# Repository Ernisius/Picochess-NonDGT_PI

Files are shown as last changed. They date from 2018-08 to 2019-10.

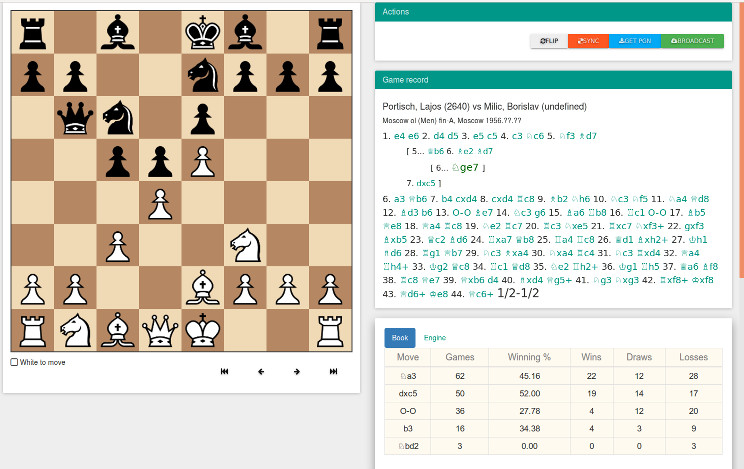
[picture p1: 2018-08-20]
test/webserver73.jpg

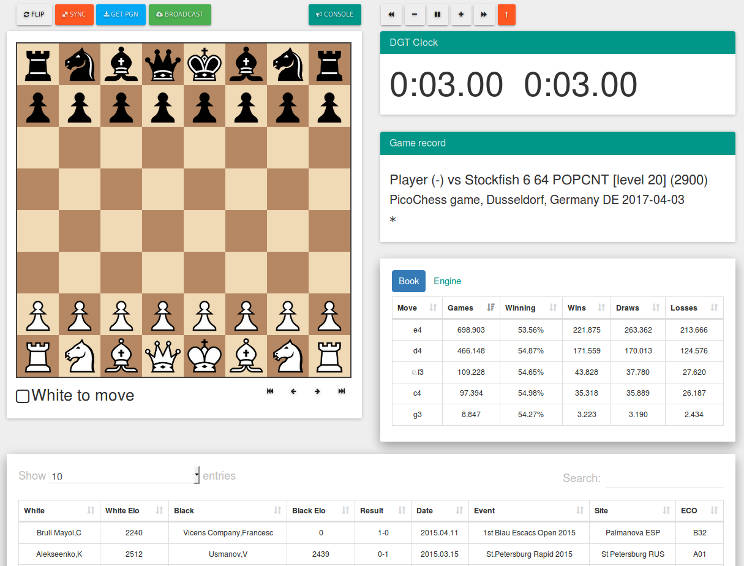
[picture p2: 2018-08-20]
test/webserver85.jpg

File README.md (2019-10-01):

PicoChess
=========

This is quite a complicated project.
I recommend you do not attempt it unless you have some knowledge of digital electronics, Arduino C programming and Python programming.
Without These skills you will find it difficult to locate any wiring or component errors.

It requires a I2c 20*4 LCD display connected to the raspberry pi via I2c.

Functionality.
To scan the reed switches, the Arduino uses a 4017 chip to set each row in turn  to + 5v, Then reads the columns into the arduino via the shift register. 
(nb It doesn't start to monitor buttons or reed matrix until it detects the pieces are set up to starting chess position, comment out the newgame line in the startup code to bypass this check.)
When a reed swith opens or closes the led for that square are flashed.
The arduino also monitors the buttons in the same way.
It sends "B:n" for a button change or move (eg "D2D4") to the pi via the usb port.

To test the board, monitor Arduino serial to make sure it is sending the expected messages.

To configure the raspberry pi follow these steps.

Download the last free picochess image from the picochess website. (version N). 
remove or rename /usr/picochess ( to stop this from autostarting when the pi boots.)
download the python code here and copy it to home on the pi.
After rebooting start with 
python3 picochess.py.

picochess is well documented on the picochess website.

When everythin is working you can move the picochess directory to /usr so it starts automatically on boot.

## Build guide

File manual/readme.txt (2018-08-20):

ShortManual.pdf contains a PicoChess manual that fits to one A4 page. Print it and 
store it under the board.

If you want to edit the file simply open ShortManual.odt. Make sure you have
the required fonts installed and at the printing dialog select PageLayout -> 
Pages per sheet = 2 and select "draw border".

Have fun.

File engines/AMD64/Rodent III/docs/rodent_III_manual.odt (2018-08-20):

Rodent III UCI

# Introduction

There are different kinds of chess engines. Some are programmed for strength. Komodo by Mark Lefer, Larry Kaufman and late Don Dailey has been able to beat human grandmasters giving them material odds. Some, like Stockfish, merge the oursuit of strength with adherence to software engineering principles. Some are programmed to prove a research hypothesis. Giraffe by Matthew Lai plays strong chess using neural networks for evaluation and highly unusual search algorithm. Some are programmed for style, like legendary Chess System Tal by Chris Whittington.

Rodent III has been programmed for tunability. You can turn it into a crazy attacker, an old-fashioned positional player, or a sparring partner for Your kids. Its tuning options are both intuitive and relevant from the chess point of view, making it a perfect free replacement of commercial programs.

# Facts and numbers

Rodent III is an open source chess engine by Pawel Koziol, licensed under GPL 3.0. It is based on a much weaker engine Sungorus 1.4 by Pablo Vazquez (https://sites.google.com/site/sungorus/). This makes it a derivative work.

Rodent III is just a chess engine, so in order to enjoy it you will need a graphical user interface (GUI). Some of possible choices are: Winboard, Arena, TarraschGUI (http://www.triplehappy.com/), ChessGUI. If You are using another GUI, You should be fine as long as it understands UCI protocol (which is usually the case, since top engines like Stockfish and Komodo use it).

Rodent's strength probably exceeds 2920 Elo on the CCRL (http://www.computerchess.org.uk/ccrl/4040/) scale. This should allow the engine to hover slightly above the 50th place on CCRL and CEGT rating lists. You can conclude that Rodent III is a decent engine, albeit far from the top dogs or from aspiring engines like Fizbo or ICE.

# Origins

Rodent III is a derivative of much weaker, yet very cleanly written engine Sungorus by Pablo Vazquez (https://sites.google.com/site/sungorus/). Its concise and logical code served as a base to add further enhancements.

Throughout the developement cycle, a lot of knowledge from other open-source programs has been added. These inspirations include (in alphabetic order):

Andscacs – penalty for bishops that cannot reach enemy half of the board

Crafty – material imbalance table

DiscoCheck – evaluation of hanging pieces (extended also to defended pieces with smaller weights).

Fruit (via Toga log user manual) – many evaluation weights, including piece square tables (PstStyle = 1 / "classic") and mobility values (MobilityStyle = 1 / "linear"). Fruit values served as reasonable first guesses and some of them were subsequently retuned.

Gambit Fruit – king tropism weights.

Hakapeliitta – basis for piece square tables ( PstStyle = 0 / "quirky" is symmetric and tweaked version of Hakapeliitta tables)

Senpai – implementation of aspiration windows and late move pruning

Stockfish – late move reduction depths, the way of initializing king safety table.

Texel – pawn island evaluation

Toga II 3.0 – razoring implementation and forwardness evaluation (in Toga II it is called "space").

# Contributors

These people helped to improve Rodent

Jim Ablett supplied Android compiles in the past

Graham Banks made a funny, cartoon-like logo

Matthew R. Brades, Denis Mendoza and Martin Sedlak supplied Linux compiles of some 1.x versions

Lucas Braesch prompted me repeteadly to maintain Linux compatibility

Dann Corbit has sent a patch allowing to use popcount intrinsics and fast 64-bit compiles, pointed some bugs.

Jon Dart supplied a Linux patch of some bitboard functions

Kestutis Gasaitis made a thorough code inspection of 0.xx versions, spotting bugs and suggesting improvements.

Raimar Goldschmidt supplied several bugfixes and created personality testing framework

Dave Kaye prepared Rodent II to be compiled under Linux

Denis Mendoza created a logo featuring Speedy Gonzales

Ferdinand Mosca created very funny KingHunter personality

Brendan J. Norman created Henny and Remy personalities and reviewed Rodent on his blog

Frank Quasinsky tested Rodent II for FCP rating list

Roman T. Sovanyan created Rodent Risky branch, and his contribution has been accepted

Pablo Vazquez has kindly allowed me to use the codebase of Sungorus to start this project

# Notes about recent release

Rodent III is a complete rewrite. It has been rather draining to do it relatively soon after a rewrite of Rodent II, but unfortunately I failed several times trying to add multicore support to that codebase.

# basic.ini

As it has been stated before, Rodent allows its users to modify several options influencing its playing style. The way of accessing all of them may seem a little clumsy. It is a result of an attempt to have the best of both worlds: instantly accessible predefined styles for a casual user and a possibility to tweak the engine for those who like it.

The choice between these scenarios must be made in basic.ini file. That file does not initialize the engine itself, but drastically changes the way how it talks to the GUI. There are two setups: "HIDE_OPTIONS" and "SHOW_OPTIONS". The first lets the user play with predefined personalities, the second – to set them manually via UCI options.

The second choice made in basic.ini relates to HIDE_OPTIONS mode only. The string "PERSONALITY_BOOKS" means that opening books are read from personality files. This works fine under Windows, but under Linux you must actually type correct paths to opening books in the personality files. The string "GENERAL_BOOKS", on the other hand, allows to set opening book independently and orders the engine to ignore book settings from personality file.

The third choice is between "ELO_SLIDER" and "NPS_BLUR". If ELO_SLIDER setting is in effect, user gets the chance to set engine's Elo via standard UCI_Elo option. If he opts for NPS_BLUR, he gets two independent parameters – nodes per second limit and the pseudo-random value added to evaluation function output. The first setting is more intuitive to use, the second one gives more liberty to the user (see hilarious "Drunk" personality with full tactical strength and hopelessly twisted evauation).

# UCI options for "HIDE_OPTIONS" mode

In "HIDE_OPTIONS" mode Rodent is initialized by a personality file, which uses the same syntax as UCI parser. Personality files can invoke the other (which may be useful if You want to change just one or two parameters). Options will be described in the section "UCI options in SHOW_OPTIONS mode" below. A sample personality will be shown on the next page.

; Marshall personality for Rodent III chess engine

; by Pawel Koziol

; hommage to Frank Marshall (1877-1944)

; very high attack, very high mobility, sacrificial, likes knights

setoption name Strength value 2737

setoption name PawnValue value 100

setoption name KnightValue value 335

setoption name BishopValue value 335

setoption name RookValue value 500

setoption name QueenValue value 1000

setoption name KeepPawn value 0

setoption name KeepKnight value 0

setoption name KeepBishop value 0

setoption name KeepRook value 0

setoption name KeepQueen value 0

setoption name BishopPair value 50

setoption name KnightPair value -10

setoption name ExchangeImbalance value 25

setoption name KnightLikesClosed value 6

setoption name RookLikesOpen value 3

setoption name Material value 90

setoption name OwnAttack value 150

setoption name OppAttack value 100

setoption name OwnMobility value 150

setoption name OppMobility value 100

setoption name KingTropism value 25

setoption name PiecePlacement value 100

setoption name PiecePressure value 100

setoption name PassedPawns value 100

setoption name PawnStructure value 90

setoption name Lines value 100

setoption name Outposts value 100

setoption name Fianchetto value 0

setoption name PawnShield value 100

setoption name PawnStorm value 100

setoption name Forwardness value 100

setoption name DoubledPawnMg value -12

setoption name DoubledPawnEg value -24

setoption name IsolatedPawnMg value -10

setoption name IsolatedPawnEg value -20

setoption name IsolatedOnOpenMg value -10

setoption name BackwardPawnMg value -8

setoption name BackwardPawnEg value -10

setoption name BackwardOnOpenMg value -8

setoption name PstStyle value 1

setoption name MobilityStyle value 0

setoption name NpsLimit value 0

setoption name EvalBlur value 0

setoption name Contempt value 0

setoption name SearchSkill value 10

setoption name SlowMover value 100

setoption name Selectivity value 175

setoption name BookFilter value 20

setoption name GuideBookFile value books/players/marshall.bin

setoption name MainBookFile value books/hist/_pre30.bin

# Available personalities

Depending on the Rodent II distribution, You will obtain a set of personalities – predefined playing styles, often together with tailormade opening books. That is where Rodent's powerful and expressive option set really shines. For user's convenience, personalities are grouped in folders. Again, not every distribution package will contain all the folders. Broad outline of what to expect is shown below.

Personalities from the folder "famous" try to reenact the famous players.

"masters" are accomplished players in 2000-2300 range.

"league" contains players in 1700-2000 Elo range, often with certain quirks.

"club" players are meant to be in 1400-1700 Elo range.

"school" players are probably 1200-1400 Elo and they are prone to tactical mistakes.

"kids" folder packs even weaker players.

"fun" folder contains rather unusual opponents, some of them quite strong, but decidedly quirky

# UCI options in SHOW_OPTIONS mode

These options can be accessed in two ways. SHOW_OPTIONS written in basic.ini asks GUI to display a full set of UCI options. Personality files also use the same syntax as the UCI options parser. Possible choices include:

## Material options:

### QueenValue, RookValue, BishopValue, KnightValue, PawnValue

material values, expressed in centipawns. Interesting effects can be obtained by slightly changing bishop, knight and rook value. It is even possible that default valuess are not perfect, and that someone might come up with a better set of parameters (if I were to guess, increasing bishop's value might help).

KeepQueen, KeepRook, KeepBishop, KeepKnight, KeepPawn

preference for a given piece for the computer side. These values should be rather low.

Usage guidelines: KeepQueen = 20 is generally a good addition for aggressive personalities, since Rodent does not evaluate king attacks for the side without a queen. KeepPawn value of 2 or 3 together with KeepKnight set at 5 and KeepBishop set at -5 should be a good starting point for a personality that likes closed positions.

BishopPair

basic bonus for a Bishop pair. Default 50 is a reasonable value.

Usage guidelines: You might lower it emulating Nimzowitsch or Tchigorin.

KnightPair

for best play this value should be negative.

Usage guidelines: making it positive has interesting, if weakening effect on engine's personality, as long as opening book allows Rodent to keep its options open.

ExchangeImbalance

this bonus is applied to a side is exchange up (having a rook against a minor piece).

Usage guidelines: Lowering it pr setting it to a negative value makes the engine more inclined to exchange sacrifices. Useful if You want to emulate Petrosian (coupled with defensive play and preference for closed positions) or Topalov (coupled with attacking play).

KnightLikesClosed

a bonus given for each pawn if a knight of the same side is present. Actually it is tuned in such a way that knight gains value with 5 or more pawns on the board, and loses otherwise. This option should generally have a single-digit value (default is 6).

Usage guidelines: KnightLikesClosed may sound like a dry, technical option, but its effects are rather interesting: increasing it causes the engine to love and cherish its knights, and in case it ends with knight(s) against bishop(s) it urges Rodent II to keep as many pawns as possible, thus keeping position closed. Predefined "Hedgehog" personality makes use of this trick.

RookLikesOpen

rooks gain power with more open files available, and therefore with less pawns on the board. Both this and the previous option come from the classic article Evaluation of material imbalances by GM Larry Kaufman.

Material

percentage of material value used in actual evaluation. This idea comes from Rhetoric chess engine.

Please note that options described above do not display a full set of bad trade penalties – and that all of them, visible or not, are scaled by Material weight to ensure consistency.

Usage guidelines: Use it with caution! 90% is enough to see a lot of pawn sacrifices without compromising playing strength, anything below that leads to much weaker, but very entertaining play style.

## Positional options

PiecePlacement

basic positional score from piece/square tables, kings not included. Explanation for non-programmers is that raising it exaggerates the effect defined by PstStyle, whereas lowering it makes engine more dependent on mobility evaluation.

OwnMobility

percentage of mobility value for engine side.

OppMobility

percentage of mobility value for non-engine side.

OwnAttack

percentage value of engine's king attack.

OppAttack

percentage value of opponent's king attack.

Usage guidelines: Mobility and attack options may be set independently to create asymmetric evaluation. This is the core of personality tuning mechanism. The engine can concentrate on carrying out own attacks, on preventing opponent's agression, on activating own pieces or on blocking enemy movements.

Fiddling with mobility can also have an interesting side effect: if opponent's mobility weight is bigger, engine will be slightly more inclined to exchange pieces. You might want to compensate this effect by using small positive values for keeping own pieces on the board.

Since Rodent's evaluation is rather speculative, value around 150 would already create a ferocious attacker. However, personalities created by Ferdinand Mosca (Kinghunter) and Brendan J. Norman (Henny, Remy) successfully use even higher values.

KingTropism

percentage of value awarded for piece proximity to enemy king. Pieces that are far get a penalty, those that are near get a bonus, different weights are used for each piece (there ar two sets: for midgame and for endgame). Exact values are derived from GambitFruit. Initially I thought that it is only a "flavour" option, but tests have shown that low values tend to score slightly better than 0.

Usage guidelines: aggressive personalities with high tropism and low tropism behave differently: the first kind amasses pieces around the enemy king, the other one shoots from afar. Negative king tropism might make sense for certain positional personalities (Petrosian rather than Nimzowitsch), but its impact is untested.

PiecePressue

weight for a bonus for attacking enemy pieces.

PawnStructure

percentage of penalty for isolated, backward and doubled pawns, as well as for pawns supporting each other (defended or standing side by side).

Usage guidelines: Increasing this option results in more tight game and may be suitable for some of the positional personalities.

PassedPawns

percentage of bonus for passed and candidate passed pawns. Engine increases this bonus for connected passers, decreases it for blocked passers and makes a correction for control of a stop square.

Outposts

weight of a bonus for occupying good squares immune from attacks by enemy pawns or defended by own pawns. This deals with positioning of minor pieces.

Usage guidelines: this value might be increased for positional personalities, but it is not strictly necessary.

Lines

weight of a bonuses for open files, semi-open files and major pieces on the 7th rank.

Pawn shield

this option determines engine's desire to protect king with own pawns.

Pawn storm

this option determines the willingness to attack enemy king with pawns.

Forwardness

this option determines the bonus for placing pieces on enemy half of the board (generally: the more, the merrier and stronger pieces have bigger weight)

Fianchetto

Bonus for a fianchetoed bishop near own king. Default is 0, but even ludicrously high values like 50 tend to test rather well.

Pst style

this option is rather difficult to describe – it makes the engine choose between three different sets of piece/square tables. These are the backbone of evaluation function, telling which piece belongs where. The available choices are likely to be expanded, but for now three distinct styles are available:

Number in UCI options dialog | Name in personality creator | About
0 | quirky | dynamic, likes advancing edge pawns
1 | classic | likes to centralize pieces
2 | normal | balanced style
3 | blunt | Weaker, primitive, centralizing

MobilityStyle

This options gives two possiblilties. Mobility can be either linear (gain from 1 to 2 possible moves is the same as from 7 to 8) or decreasing (improving low mobility scores comes before improving high mobility scores). In personality creator, we use the aforementioned names, in UCI options dialog 0 is linear and 1 is decreasing.

## Other options

BookFilter

irrelevant for eval tuning, influences usage of Polyglot books by eliminating moves with the value lesser than a given percentage of best move's value. Read more in "Opening book" section.

NPS

nodes per second. This option is meant to slow the engine down, and used to create weak personalities. This needs more testing, but NPS of about 5000 puts Rodent II somewhere within the 1600-1800 Elo range (FIDE scale).

EvalBlur

Random value added to evaluation function, used to create weak personalities.

Contempt

Represents the unwillingness to draw. For example, value "12" means that in the opening position Rodent will prefer to be 11 centipawns behind than to accept a draw by repetition.

SlowMover

percentage modifier for time usage. Values < 100 make the engine play faster at the beginning of the game, values > 100 make it use more time.

SearchSkill

Another way of weakening the engine. Search skill lower than 10 means that certain search techniques are disabled.

Search skill 1 – transposition table enabled

Search skill 2 – null move enabled

Search skill 3 – LMR of quiet moves enabled

Search skill 4 – razoring enabled

Search skill 5 – futility pruning enabled

Search skill 6 – late move pruning enabled

Search skill 7 – aspiration window enabled

Search skill 8 – static null move enabled

Search skill 9 – reduction of bad captures

Search skill 10 – null move verification

RiskyDepth

Contribution from Roman T. Savonyan. If above 0, it denotes depth at which score is modified by a formula that makes engine to like risky continuations.

Selectivity

Determines how often Rodent uses pruning and reduction heuristics at move level. This option affects late move reduction, late move pruning and futility pruning, but has no effect on null move pruning and razoring. Minimum value of 0 switches these techniques off, maximum value of 200 means using them on any eligible move. Values in between indicate how often a move that has been successfull in the past searches is exempt from pruning. Default value is 175.

Usage guidelines: Default has been tested to be stronger than 150 and 200. Values around 100 can be used to emulate primarily positional players.

# Describing personalities

When creating new personality for Rodent II, it might be a good idea to prepare a description, telling the user what to expect. Description can be brief (just a couple of adjectives) or more "artistic" (describing a set of parameters as if it was a human character). Here I propose a couple of terms. Please treat them as guidelines, not as

Proposed term | Meaning
active | OwnMobility increased
restricting, grinder | OppMobility increased
aggressive | OwnAttack increased
careful, prophylactic | OppAttack increased
dynamic | both OwnAttack and OwnMobility increased
materialist | MaterialWeight > 100
sacrificing | MaterialWeight at about 90
romantic | MaterialWeight < 90
classical | PiecePlacement > 100
improvising | PiecePlacement < 100
solid | PawnStructure > 100, possibly also Outposts > 100
undervalues/overvalues X | piece value different from default
likes blocked positions | KnightLikesClosed > 6 KeepPawn > 0
moderate | NPSLimit at about 2000
weak | NPSLimit < 1000
careless | high evalBlur
fast | MoveTime < 100
slow | MoveTime > 100

# Opening book

Rodent uses two Polyglot (*.bin) books in succession. The idea behind this design is that first book may be a narrow, handmade repertoire book, whereas the second one, usually bigger and more general, constitutes a fallback option.

Rodent has a unique feature allowing it to filter moves that would be used with the frequency lower than n% of best move frequency. Default settings use n = 10. If you set it to 100%, engine will pick only the book moves played with the greatest frequency. Most of the time it will be just one move, sometimes two or three. When using rodent.bin, 50% will give you a narrow book exploring only major alternatives.

Elo | NPS | Rejected version – weak below 2000 | Blur
1000 | 50 | 54 | 200
1100 | 130 | 58 | 180
1200 | 210 | 64 | 160
1300 | 290 | 72 | 140
1400 | 370 | 98 | 120
1500 | 450 | 128 | 100
1600 | 660 | 186 | 80
1700 | 740 | 303 | 60
1800 | 1000 | 540 | 40
1900 | 2000 | 1007 | 20
2000 | 4000 | 3800 | 0
2100 | 8000 | 7560 | 0
2200 | 16000 | 15051 | 0
2300 | 32000 | 30000 | 0
2400 | 64000 | 60000 | 0
2500 | 128000 | 241000 | 0
2600 | 256000 | 482000 | 0
2700 | 512000 | 964000 | 0
2800 | 1mln+ | 1 mln+ | 0

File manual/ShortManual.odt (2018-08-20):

## Choosing opening books (selection with black queen)

Opening books are set with the extra M. (Remove the extra m if it is still on the board)

Ma3 | Mb3 | Mc3 | Md3 | Me3 | Mf3 | Mg3 | Mh3
No book | ECO A – Flank Openings | ECO B – Semi Open Openings | ECO C – Open Openings | ECO D – Closed Openings | ECO E – Indian Openings | Fun Book | Varied (Default)
Ma4 | Mb4 | Mc4 | Md4 | Me4 | Mf4 | Mg4 | Mh4
GM games | Perfor-mance | Stockfish optimized | Anand book | Korchnoi book | Larsen book | Pro book | GM 2001

## Setting up time controls (selection with white queen)

You can choose them by placing the extra m. (Remove the extra M if it is still on the board). Blitz 5 minutes per game is set as default.

### Movetime (seconds per move)

ma6 | mb6 | mc6 | md6 | me6 | mf6 | mg6 | mh6
1 sec | 3 sec | 5 sec | 10 sec | 15 sec | 30 sec | 60 sec | 90 sec

### Gametime (minutes per game)

ma4 | mb4 | mc4 | md4 | me4 | mf4 | mg4 | mh4
1 min | 3 min | 5 min | 10 min | 15 min | 30 min | 60 min | 90 min

### Fischer Time (minutes per game plus an increment per move)

ma3 | mb3 | mc3 | md3 | me3 | mf3 | mg3 | mh3
1 min plus 1 sec inc | 3 min plus 2 sec inc | 5 min plus 3 sec inc | 10 min plus 5 sec inc | 15 min plus 10 sec inc | 30 min plus 15 sec inc | 60 min plus 20 sec inc | 90 min plus 30 sec inc

## Engine selection (selection with black queen)

Ma6 | Mb6 | Mc6 | Md6 | Me6 | Mf6 | Mg6 | Mh6
Stockfish 8 | Texel 1.07 | Arasan 20.3 | Rodent III 0.233 | Zurichess neuchatel | WyldChess 1.5 | Galjoen 0.37 | Sayuri 2017.12.16

## Choosing skill level (selection with black queen)

Put the extra M on your DGT board to select skill level. If no skill level is selected, PicoChess uses the highest level by default. (Remove the extra m if it is still on the board). Please note that not all chess engines support levels.

Ma5 | Mb5 | Mc5 | Md5 | Me5 | Mf5 | Mg5 | Mh5
Level 0 (Stockfish) | Level 3 (Stockfish) | Level 6 (Stockfish) | Level 9 (Stockfish) | Level 12 (Stockfish) | Level 15 (Stockfish) | Level 18 (Stockfish) | Level 20 (Stockfish)

## Playing / Training Modes (selection with white queen)

When using these modes, please be patient and don’t rush moves. Allow a few seconds for the scores and moves to appear.

Game mode is enabled by putting ma5 square. This is the default mode. You can play against the computer.

Brain mode is enabled by putting mb5 square. This is similar to game mode but the computer is thinking on your time too. This system is also known as „Permanent Brain“ therefore its name.

Analysis mode (enabled by mc5): the computer is watching the game; it does not play itself. The clock continually displays the best move for the side to play.

Kibitz mode (enabled by md5): the computer is watching the game; it does not play itself. The clock continually displays the position score together with the depth.

Observe mode (enabled by me5): the computer is watching the game; it does not play itself. The clock displays the remaining thinking time for both sides.

Ponder mode (enabled by mf5): the computer is watching the game, it does not play itself. The clock displays the best move for the side to play in rotation with the position score together with the depth.

Remote mode (enabled by mh5): this mode will allow you to play against someone over internet. The remote player using the webserver whereas the other player using the pieces as normal to enter moves.

## Start a new game

Simply place all pieces to the start position. Adjust your options (e.g. time control, strength, ...) and start playing. If you

want to play Black, press the lever on the clock.

## Update picochess

You can either set the „update flag“ inside picochess.ini or you can press the middle button during the startup when „picochess“ is displayed. This will let you choose which version you want to get (you can upgrade or downgrade). You need a working iNet connection for this to work.

## Shutdown

From the start position, replace the white n with the extra white m. This will shut down the Raspberry. It takes a few seconds until the blue light turns off. You can also do it with only the two m on the board (on e1,d1) and all other pieces removed from the board.

## Resign a game or declare draw

Placing the two kings on opposite centre squares will signal a resignation:

White wins: If both kings on white (e4,d5), the result is white wins and the game recorded 1-0

Black wins: If both kings on black (d4,e5), the result is black wins and the game recorded 0-1

Draw: Placing the kings on adjacent centre squares (d4&e4;d5&e5) on the same rank signals a draw and

the game recorded 1/2-1/2. The fourth and fith rank must be clear of other pieces - only kings.

PicoChess Short Manual v0.9l

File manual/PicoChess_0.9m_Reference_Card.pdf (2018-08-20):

PicoChess 0.9m Reference Card | January 2018

### Choosing an Engine

8 | | | rmblkans
7 | | | opopopop
6 | | | 0ZqZ0Z0Z
5 | | | Z0Z0Z0Z0
4 | | | 0Z0Z0Z0Z
3 | Z0Z0Z0Z0 2 | POPOPOPO 1 | SNAQJBMR
a | b | c | d | e | f | g | h

black queen

a6 | Stockfish 8 (‘081017’) | default
b6 | Texel 1.07
c6 | Arasan 20.3.0
d6 | Rodent iii 0.233
e6 | Zurichess neuchatel (‘master’)
f6 | WyldChess 10062017
g6 | Galjoen 0.37.2
h6 | Sayuri 2017.12.16

Example: Arasan 20.3.0

### Choosing a Level

8 | | | rmblkans
7 | | | opopopop
6 | | | 0Z0Z0Z0Z
5 | | | Z0ZqZ0Z0
4 | | | 0Z0Z0Z0Z
3 | Z0Z0Z0Z0 2 | POPOPOPO 1 | SNAQJBMR
a | b | c | d | e | f | g | h

black queen

a5 | Level 0 (= weakest)
b5 | Level 3
c5 | Level 6
d5 | Level 9
e5 | Level 12
f5 | Level 15
g5 | Level 18
h5 | Level 20 (= strongest) | default

* Not all engines support levels: Rodent iii has
‘personalities’ and Zurichess has ‘handicaps’. | Example: Level 9

### Choosing an Opening Book

black queen

a3 | No book
8 | | | rmblkans
7 | | | opopopop
6 | | | 0Z0Z0Z0Z
5 | | | Z0Z0Z0Z0
4 | | | 0Z0Z0Z0Z
3 | Z0Z0Z0l0 2 | POPOPOPO 1 | SNAQJBMR
a | b | c | d | e | f | g | h
b3 | eco A: flank openings
c3 | eco B: semiopen games
d3 | eco C: open games + French
e3 | eco D: closed games
f3 | eco E: Indian games
g3 | Fun
h3 | Varied | default
a4 | gm 1950
b4 | Performance
c4 | Stockfish
d4 | Anand
e4 | Korchnoi
f4 | Larsen | Example: Opening Book ‘Fun’
g4 | Pro
h4 | gm 2001

### Choosing a Time Control

8 | | | rmblkans
7 | | | opopopop
6 | | | 0Z0Z0Z0Z
5 | | | Z0Z0Z0Z0
4 | | | 0Z0ZQZ0Z
3 | Z0Z0Z0Z0 2 | POPOPOPO 1 | SNAQJBMR
a | b | c | d | e | f | g | h

white queen

a6 | Fixed: 1 s / move
b6 | 3 s / move
c6 | 5 s / move
d6 | 10 s / move
e6 | 15 s / move
f6 | 30 s / move
g6 | 60 s / move
h6 | 90 s / move
a4 | Blitz: 1 min / game
b4 | 3 min / game | Example: Blitz 15 min / game
c4 | 5 min / game | default
d4 | 10 min / game
8 | | | rmblkans
7 | | | opopopop
6 | | | 0Z0Z0Z0Z
5 | | | Z0Z0Z0Z0
4 | | | 0Z0Z0Z0Z
3 | L0Z0Z0Z0 2 | POPOPOPO 1 | SNAQJBMR
a | b | c | d | e | f | g | h
e4 | 15 min / game
f4 | 30 min / game
g4 | 60 min / game
h4 | 90 min / game
a3 | Fischer: 1 min + 1 s / move
b3 | 3 min + 2 s / move
c3 | 5 min + 3 s / move
d3 | 10 min + 5 s / move
e3 | 15 min + 10 s / move
f3 | 30 min + 15 s / move
g3 | 60 min + 20 s / move
h3 | 90 min + 30 s / move | Example: Fischer 1 min + 1 s / move

### Choosing a Play Mode

8 | | | rmblkans
7 | | | opopopop
6 | | | 0Z0Z0Z0Z
5 | | | L0Z0Z0Z0
4 | | | 0Z0Z0Z0Z
3 | Z0Z0Z0Z0 2 | POPOPOPO 1 | SNAQJBMR
a | b | c | d | e | f | g | h

white queen

a5 | Play against computer | default
b5 | Brain mode
c5 | Analysis mode
d5 | Kibitz mode
e5 | Observe mode
f5 | Ponder mode
h5 | Remote mode

Example: Play against computer

### Adjudicating a Game

8 | | | 0Z0Z0s0Z
7 | | | ZrZ0ZBSp
6 | | | pZpZ0Z0Z
5 | | | Z0Z0j0Z0
4 | | | 0Z0J0Z0Z
3 | O0ZPZ0Z0 2 | 0O0Z0Z0Z 1 | Z0Z0Z0Z0
a | b | c | d | e | f | g | h

both kings

First, clear the fourth and fifth ranks.
Then, place both kings:
- on e4 and d5 = White wins
- on d4 and e5 = Black wins
- on d4 and e4 = draw
- on d5 and e5 = draw

Example: Black wins

### Shut Down the Computer

8 | | | rmblkans
7 | | | opopopop
6 | | | 0Z0Z0Z0Z
5 | | | Z0Z0Z0Z0
4 | | | 0Z0Z0Z0Z
3 | Z0Z0Z0Z0 2 | POPOPOPO 1 | SNAQLBMR
a | b | c | d | e | f | g | h

white queen

In starting position,
replace the white king
with the spare white queen to power off the computer.

Also works with empty board and both white queens on
d1 and e1.

Example: Shut down computer

### Reboot the Computer

8 | | | rmblqans
7 | | | opopopop
6 | | | 0Z0Z0Z0Z
5 | | | Z0Z0Z0Z0
4 | | | 0Z0Z0Z0Z
3 | Z0Z0Z0Z0 2 | POPOPOPO 1 | SNAQJBMR
a | b | c | d | e | f | g | h

black queen

In starting position,
replace the black king
with the spare black queen to reboot the computer.

Also works with empty board and both black queens on
d8 and e8.

Example: Reboot computer

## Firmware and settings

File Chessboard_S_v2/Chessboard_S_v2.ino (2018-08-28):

#include "Adafruit_LEDBackpack.h"
#include <Wire.h>
#include "Adafruit_GFX.h"


Adafruit_LEDBackpack matrix = Adafruit_LEDBackpack();

#define White 0
#define Black 1;
#define  SR_Sin  6  //4021 #3
#define  PSCont  8  //4021 #9
#define  SR_SCLK  7  //4021 #10

#define  Cntr_CLK 4   //4017 #14
#define  Cntr_CLR 5   //4017 #15  //4017 #13 grnd

#define B1 2
#define B2 3
#define B3 11
#define B4 12

#define Enc_In1 9
#define Enc_In2 10

//for encoders
#define DIR_CCW 0x10
#define DIR_CW 0x20

const unsigned char ttable[7][4] = {            //for encoders
  {0x0, 0x2, 0x4, 0x0}, {0x3, 0x0, 0x1, 0x10},
  {0x3, 0x2, 0x0, 0x0}, {0x3, 0x2, 0x1, 0x0},
  {0x6, 0x0, 0x4, 0x0}, {0x6, 0x5, 0x0, 0x20},
  {0x6, 0x5, 0x4, 0x0},
};
int speakerPin = 13;

int numTones = 10;
int tones[] = {261, 277, 294, 311, 330, 349, 370, 392, 415, 440};
//            mid C  C#   D    D#   E    F    F#   G    G#   A

char * boardsquare[] = {"A1", "B1", "C1", "D1", "E1", "F1", "G1", "H1",
                        "A2", "B2", "C2", "D2", "E2", "F2", "G2", "H2",
                        "A3", "B3", "C3", "D3", "E3", "F3", "G3", "H3",
                        "A4", "B4", "C4", "D4", "E4", "F4", "G4", "H4",
                        "A5", "B5", "C5", "D5", "E5", "F5", "G5", "H5",
                        "A6", "B6", "C6", "D6", "E6", "F6", "G6", "H6",
                        "A7", "B7", "C7", "D7", "E7", "F7", "G7", "H7",
                        "A8", "B8", "C8", "D8", "E8", "F8", "G8", "H8"
                       };
int move_to, move_from;
bool computermove = false;
int keychanged;
int buttonmask;
bool lifted;
int boardmatrix[64];     //kb matrix

unsigned long lastDebounceTime = 0;  // the last time the output pin was toggled
unsigned long debounceDelay = 200;    // the debounce time; increase if the output flickers

void setup()
{
  pinMode(SR_Sin , INPUT);
  pinMode(PSCont, OUTPUT);
  pinMode(SR_SCLK, OUTPUT);

  pinMode(Cntr_CLK, OUTPUT);
  pinMode(Cntr_CLR, OUTPUT);

  pinMode(Enc_In1, INPUT_PULLUP);
  pinMode(Enc_In2, INPUT_PULLUP);

  pinMode(B1, INPUT_PULLUP);
  pinMode(B2, INPUT_PULLUP);
  pinMode(B3, INPUT_PULLUP);
  pinMode(B4, INPUT_PULLUP);

  Serial.begin(115200);
  Serial.setTimeout(50);
  matrix.begin(0x70);  // pass in the address
  matrix.clear();
  //matrix.blinkRate(HT16K33_BLINK_2HZ);

  newgame(White);
  fillMatrix();
  matrix.writeDisplay();
}

void loop()
{

  bool buttonEnable = true;
  long buttonDelay;

  FromPython();

  if (KeyChanged())
  {
    //Serial.print(keychanged);

    FlashSquare(keychanged, 100);
    if (computermove)
    {
      MakeComputerMove(keychanged);
    }
    else
    {
      MakeUserMove(keychanged);
    }

    if (!lifted)
    {
      //Serial.println( " dropped");
      CheckBoardPosition();
    }
    // else Serial.println(" Lifted");
  }

  rotary_process();

  GetButtonMask();
}
void MakeComputerMove(int square)
{
  if (lifted)
  {
    if (square == move_from)
    {
      // beep(450, 100);
      LightSquare(move_to, true);
      matrix.writeDisplay();
    }
    else if (square == move_to)  //remove taken piece
    {
      //do nothing
    }
    else
    {
      //beep(550, 150);
      //beep(450, 100); //wrong
    }
  }

  else   //dropped
  {
    if (square == move_to)
    {
      // beep(350, 100);
      matrix.clear();
      matrix.writeDisplay();
      computermove = false;
      ToPython("Done");
    }
  }
}
void MakeUserMove(int square)
{
  static bool startsquare;
  if (lifted)
  {
    if (!startsquare)
    {
      //beep(500, 100);
      LightSquare(square, true);
      matrix.writeDisplay();
      move_from = square;
      startsquare = true;
    }
    else
    {
      // remove oppenents piece
    }
  }
  else  //dropped
  {
    if (move_from != square)    //!put back on same square
    {
      matrix.clear();
      String move = boardsquare[move_from];
      ToPython(move + boardsquare[square]);
      FlashSquare(square, 100);
      //beep(400, 100);
    }
    else
    {
      FlashSquare(square, 100);  //dropped on same square
      //beep(300, 200);
    }
    startsquare = false;
  }
}
void GetButtonMask()
{
  if (millis() < lastDebounceTime + debounceDelay) return;
  static int mask;
  int switchvalue = 0;
  if (digitalRead(B1) == 0) switchvalue = switchvalue | 0b10000; //b:4
  if (digitalRead(B2) == 0) switchvalue = switchvalue | 0b1; //b:0
  if (digitalRead(B4) == 0) switchvalue = switchvalue | 0b100000; //b:5
  if (digitalRead(B3) == 0) switchvalue = switchvalue | 0b100; //b:2
  if (switchvalue != mask)
  {
    mask = switchvalue;
    lastDebounceTime = millis();
    switch (mask)
    {
      case 1:
        Serial.println("b:0");
        break;
      case 4:
        Serial.println("b:2");
        break;
      case 16:
        Serial.println("b:4");
        break;
      case 32:
        Serial.println("b:5");
        break;
      default:
        break;
    }
  }
}
void ToPython(String s)
{
  Serial.println(s);// write a string
}

void FromPython()
{
  if (Serial.available() > 2)
  {
    char data = Serial.read();

    if (data == 'F')    //from computer 'from square'
    {
      computermove = true;
      move_from = Serial.parseInt();
      LightSquare(move_from, true);
      matrix.writeDisplay();
    }
    if (data == 'T')  //from computer 'to square'
    {
      move_to = Serial.parseInt();
      computermove = true;

    }
  }
}

bool KeyChanged()
{
  int key = checkmatrix();
  if (key != 99)
  { //key changed

    boardmatrix[key] = newState;
    keychanged = key;
    if (newState == 1) lifted = false;
    else lifted = true;
    return true;
  }
  return false;
}

bool GetKeyState(int key)
{
  //int c = key / 8;
  // int r = key & 0x7;
  if (boardmatrix[key] == 1) return true;
  else return false;
}

int checkmatrix()
{
  static int lastkey;
  int key = 0;

  digitalWrite(Cntr_CLR, HIGH); //reset 4017
  digitalWrite(Cntr_CLR, LOW);

  for (int row = 0; row < 8; row++)
  {
    digitalWrite(Cntr_CLK, HIGH);  //clock 4017 -use outputs 1-9 ; not 0
    digitalWrite(Cntr_CLK, LOW);

    digitalWrite(PSCont, HIGH);   //latch paralel data
    digitalWrite(PSCont, LOW);
    for (int column = 7; column >= 0; column--)
    {
      int data = digitalRead(SR_Sin);
      if (data != boardmatrix[row * 8 + column])
      {
        key = (row * 8 + column);
        if (key == lastkey)
        {
          newState = data;
          lastkey = 0;
          return (key);
        }
        else
        {
          lastkey = key;
        }
      }
      digitalWrite(SR_SCLK, HIGH);            //next bit
      digitalWrite(SR_SCLK, LOW);
    }
  }
  //digitalWrite(Cntr_CLR, HIGH); //reset 4017
  //digitalWrite(Cntr_CLR, LOW);
  return (99);
}

// reads the current switch states into matrix
void fillMatrix()
{
  digitalWrite(Cntr_CLR, HIGH); //reset 4017
  digitalWrite(Cntr_CLR, LOW);

  for (int row = 0; row < 8; row++)
  {
    digitalWrite(Cntr_CLK, HIGH);  //clock 4017 -use outputs 1-9 ; not 0
    digitalWrite(Cntr_CLK, LOW);

    digitalWrite(PSCont, HIGH);   //latch paralel data
    //PORTB = PORTB | B00000001;
    //delayMicroseconds(1);
    digitalWrite(PSCont, LOW);
    //PORTB = PORTB & B11111110;
    for (int column = 7; column >= 0; column--)
    {
      int data = digitalRead(SR_Sin);
      boardmatrix[row * 8 + column] = data;

      // PORTD = PORTD | B10000000;
      //delayMicroseconds(1);
      digitalWrite(SR_SCLK, HIGH);            //next bit
      //PORTD = PORTD & B01111111;
      digitalWrite(SR_SCLK, LOW);
    }
  }
}
void  lightled(int row, int column, bool on)
{
  if (column < 8)
  {
    if (on) matrix.displaybuffer[column] |= (1 << row);
    else matrix.displaybuffer[column] &= ~(1 << row);
  }
  else if (row < 8) //column 8
  {
    if (on) matrix.displaybuffer[row] |= (1 << 9);
    else matrix.displaybuffer[row] &= ~(1 << 9);
  }
  else  //column and row 8
  {
    if (on) matrix.displaybuffer[0] |= (1 << 10);
    else matrix.displaybuffer[0] &= ~(1 << 10);
  }
}

void FlashSquare(int square, int milliseconds)
{
  matrix.clear();
  LightSquare(square, true);
  matrix.writeDisplay();
  //beep(350,milliseconds);
  delay(milliseconds);
  LightSquare(square, false);
  matrix.writeDisplay();
}

void  LightSquare(int square, bool on)
{
  int row = int (square / 8);
  int column = square & 7;
  lightled(row, column, on);
  lightled(row + 1, column, on);
  lightled(row, column + 1, on);
  lightled(row + 1, column + 1, on);
  matrix.writeDisplay();
}

//void beep(int note1, int lengh)
//{
//  tone(speakerPin, note1);
//  delay(lengh);
//  noTone(speakerPin);
//  //delay(100);
//  //tone(speakerPin, note2);
//  //delay(50);
//  //noTone(speakerPin);
//
//}
void rotary_process()
{

  static int rpState;

  unsigned char pinstate = ((bitRead(PINB, 1)) << 1) | bitRead(PINB, 2); //Digitalpin 9&10
  rpState = ttable[rpState & 0xf][pinstate];


  if ((rpState & 0x30) == 16)
  {
    ToPython("B:3\n");

  }
  else if ((rpState & 0x30) == 32)
  {
    ToPython("B:1\n");

  }
}

void newgame(int color)
{
  int brdsetup = 0;

  while (brdsetup < 32)
  {
    fillMatrix(); //piece positions to matrix
    bool on;
    matrix.clear();

    brdsetup = 32;
    for (int i = 0; i < 16; i++)
    {
      if (!GetKeyState(i))
      {
        brdsetup--;
        LightSquare(i, true);
      }
    }
    for (int i = 48; i < 64; i++)
    {
      if (!GetKeyState(i))
      {
        brdsetup--;
        LightSquare(i, true);
      }
    }
    matrix.writeDisplay();
  }
  //
  //    beep(400, 50);
  //    delay(500);
  //    beep(400, 50);
  //    delay(500);
  //    beep(440, 300);
  computermove = false;
  if (color)   ToPython("newgame:b");
  else ToPython("newgame:w");
}
//'RNBKQBNR/PPPPPPPP/8/8/8/8/pppppppp/rnbqqbnr' = REBOOT


void CheckBoardPosition()
{
  fillMatrix(); //piece positions to matrix
  int squarecount = 0;
  for (int square = 0; square < 16; square++)
  {
    if (boardmatrix[square] == 1) //occupied
    {
      squarecount++;
      //LightSquare(row * 8 + column, true);
    }
  }
  for (int square = 48; square < 64; square++)
  {
    if (boardmatrix[square] == 1) //occupied
    {
      squarecount++;
      //LightSquare(row * 8 + column, true);
    }
  }

  if (squarecount == 32)
  {
    if (boardmatrix[16] == 1)
    {
      ToPython("shutdown");  //reboot
    }
    else if (boardmatrix[17] == 1)
    {
      ToPython("reboot");  //reboot
    }
    else
    {
      computermove = false;
      ToPython("newgame:w");
    }

  }
}

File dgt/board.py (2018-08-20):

# Copyright (C) 2013-2018 Jean-Francois Romang (jromang@posteo.de)
#                         Shivkumar Shivaji ()
#                         Jürgen Précour (LocutusOfPenguin@posteo.de)
#
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
import struct
import logging
import subprocess
from threading import Timer, Lock
#from fcntl import fcntl, F_GETFL, F_SETFL
#from os import O_NONBLOCK, read, path, listdir
from serial import Serial, SerialException, STOPBITS_ONE, PARITY_NONE, EIGHTBITS
import time

from dgt.util import DgtAck, DgtClk, DgtCmd, DgtMsg, ClockIcons, ClockSide, enum
from dgt.api import Message, Dgt
from utilities import RepeatedTimer, DisplayMsg, hms_time


class DgtBoard(object):

    """Handle the DGT board communication."""

    def __init__(self, device: str, disable_revelation_leds: bool, is_pi: bool, disable_end: bool, field_factor=0):
        super(DgtBoard, self).__init__()
        self.given_device = device
        self.device = device
        # rev2 flags
        self.disable_revelation_leds = disable_revelation_leds
        self.enable_revelation_pi = False
        self.is_revelation = False

        self.is_pi = is_pi
        self.disable_end = disable_end  # @todo for test - XL needs a "end_text" maybe!
        self.field_factor = field_factor % 10

        self.serial = None
        self.lock = Lock()  # lock the serial write
        self.incoming_board_thread = None
        self.lever_pos = None
        # the next three are only used for "not dgtpi" mode
        self.clock_lock = False  # serial connected clock is locked
        self.last_clock_command = []  # Used for resend last (failed) clock command
        self.enable_ser_clock = None  # None = "unknown status" False="only board found" True="clock also found"
        self.watchdog_timer = RepeatedTimer(1, self._watchdog)
        # bluetooth vars for Jessie upwards & autoconnect
        self.btctl = None
        self.bt_rfcomm = None
        self.bt_state = -1
        self.bt_line = ''
        self.bt_current_device = -1
        self.bt_mac_list = []
        self.bt_name_list = []
        self.bt_name = ''
        self.wait_counter = 0
        # keep the last time to find out errorous DGT_MSG_BWTIME messages (error: current time > last time)
        self.r_time = 3600 * 10  # max value cause 10h cant be reached by clock
        self.l_time = 3600 * 10  # max value cause 10h cant be reached by clock

        self.bconn_text = None
        # keep track of changed board positions
        self.field_timer = None
        self.field_timer_running = False
        self.channel = None

        self.in_settime = False  # this is true between set_clock and clock_start => use set values instead of clock
        self.low_time = False  # This is set from picochess.py and used to limit the field timer

    def expired_field_timer(self):
        """Board position hasnt changed for some time."""
        logging.debug('board position now stable => ask for complete board')
        self.field_timer_running = False
        self.write_command([DgtCmd.DGT_SEND_BRD])  # Ask for the board when a piece moved

    def stop_field_timer(self):
        """Stop the field timer cause another field change been send."""
        logging.debug('board position was unstable => ignore former field update')
        self.field_timer.cancel()
        self.field_timer.join()
        self.field_timer_running = False

    def start_field_timer(self):
        """Start the field timer waiting for a stable board position."""
        if self.low_time:
            wait = (0.2 if self.channel == 'BT' else 0.10) + 0.06 * self.field_factor  # bullet => allow more sliding
        else:
            wait = (0.5 if self.channel == 'BT' else 0.25) + 0.03 * self.field_factor  # BT's scanning in half speed
        logging.debug('board position changed => wait %.2fsecs for a stable result low_time: %s', wait, self.low_time)
        self.field_timer = Timer(wait, self.expired_field_timer)
        self.field_timer.start()
        self.field_timer_running = True

    def write_command(self, message: list):
        """Write the message list to the dgt board."""
        mes = message[3] if message[0].value == DgtCmd.DGT_CLOCK_MESSAGE.value else message[0]
        if not mes == DgtCmd.DGT_RETURN_SERIALNR:
            logging.debug('(ser) board put [%s] length: %i', mes, len(message))
            if mes.value == DgtClk.DGT_CMD_CLOCK_ASCII.value:
                logging.debug('sending text [%s] to (ser) clock', ''.join([chr(elem) for elem in message[4:12]]))
            if mes.value == DgtClk.DGT_CMD_REV2_ASCII.value:
                logging.debug('sending text [%s] to (rev) clock', ''.join([chr(elem) for elem in message[4:15]]))
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

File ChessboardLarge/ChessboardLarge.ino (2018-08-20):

//#include "ledmatrix.h"
#include "Switchmatrix.h"
#include <Wire.h>
#include "Adafruit_LEDBackpack.h"
#include "Adafruit_GFX.h"
#include <LiquidCrystal_I2C.h>
//I2C pins declaration
LiquidCrystal_I2C lcd(0x3f, 2, 1, 0, 4, 5, 6, 7, 3, POSITIVE); 
SwitchMatrix sw;

int White=0;
int Black=1;
int buttonsave;
int move_to, move_from;

Adafruit_LEDBackpack matrix = Adafruit_LEDBackpack();

static long startTime = 0;  // the last time the output pin was toggled
int speakerPin = 12;
 
int numTones = 10;
int tones[] = {261, 277, 294, 311, 330, 349, 370, 392, 415, 440};
//            mid C  C#   D    D#   E    F    F#   G    G#   A

char * boardsquare[] = {"A1", "B1", "C1", "D1", "E1", "F1", "G1", "H1",
                        "A2", "B2", "C2", "D2", "E2", "F2", "G2", "H2",
                        "A3", "B3", "C3", "D3", "E3", "F3", "G3", "H3",
                        "A4", "B4", "C4", "D4", "E4", "F4", "G4", "H4",
                        "A5", "B5", "C5", "D5", "E5", "F5", "G5", "H5",
                        "A6", "B6", "C6", "D6", "E6", "F6", "G6", "H6",
                        "A7", "B7", "C7", "D7", "E7", "F7", "G7", "H7",
                        "A8", "B8", "C8", "D8", "E8", "F8", "G8", "H8"
                       };
bool computermove = false;
void setup()
{
  
  Serial.begin(115200);
  Serial.setTimeout(50);
  matrix.begin(0x70);  // pass in the address
  sw.fillMatrix();
  buttonsave=0;
  newgame(White);
  lcd.begin(20,4);//Defining 20 columns and 4 rows of lcd display
  lcd.backlight();//To Power ON the back light
//lcd.backlight();// To Power OFF the back light

  lcd.setCursor(0,0); //Defining positon to write from first row,first column .
  lcd.print("PicoChess"); 
  lcd.setCursor(0,1);  
  lcd.print("modified by Brian");
  lcd.setCursor(0,2);  
  lcd.print("");
  lcd.setCursor(0,3);  
  lcd.print("");

}

void loop() 
{
  static bool enablebuttons;
  
  FromPython();
  if(GetButtonMask())
  {
    if(sw.buttonmask==0)
    {
      enablebuttons=true;
    } 
    else if(enablebuttons)
    {
      enablebuttons=false;
      switch (sw.buttonmask)
      {
        case 1:
          ToPython("B:0");
          break;
        case 2:
          ToPython("B:1");
        break;
        case 4:
          ToPython("B:2");
        break;
        case 8:
          ToPython("B:3");
        break;
        case 16:
          ToPython("B:4");
        break;
        case 32:
          ToPython("B:5");
          //newgame(White);
        break;
        case 64:
          ToPython("B:6");
          // newgame(Black);
         break;
         case 128:
         ToPython("B:7");
         // ToPython("tb:");
        break;
      }
    }
  }
  if (sw.KeyChanged())
  {
    int key = sw.keychanged;
    bool lifted = sw.lifted;
    FlashSquare(key, 100);
    if (computermove)
    {
      MakeComputerMove(key);
    }
    else
    {
      MakeUserMove(key);
    }
    
    if (!lifted)
    {
      CheckBoardPosition();
    }
    
  }
}
void MakeComputerMove(int square)
{
  if (sw.lifted)
  {
    if (square == move_from)
    {
      // beep(450, 100);
      LightSquare(move_to);
      matrix.writeDisplay();
    }
    else if (square == move_to)  //remove taken piece
    {
      //do nothing
    }
    else
    {
      //beep(550, 150);
      //beep(450, 100); //wrong
    }
  }

  else   //dropped
  {
    if (square == move_to)
    {
      // beep(350, 100);
      matrix.clear();
      matrix.writeDisplay();
      computermove = false;
      ToPython("Done");
    }
  }
}
void MakeUserMove(int square)
{
  static bool startsquare;
  if (sw.lifted)
  {
    if (!startsquare)
    {
      //beep(500, 100);
      LightSquare(square);
      matrix.writeDisplay();
      move_from = square;
      startsquare = true;
    }
    else
    {
      // remove oppenents piece
    }
  }
  else  //dropped
  {
    if (move_from != square)    //!put back on same square
    {
      matrix.clear();
      String move = boardsquare[move_from];
      ToPython(move + boardsquare[square]);
      FlashSquare(square, 100);
      //beep(400, 100);
    }
    else
    {
      FlashSquare(square, 100);  //dropped on same square
      //beep(300, 200);
    }
    startsquare = false;
  }
}
void ToPython(String s)
{
  Serial.println(s);// write a string
}

void FromPython()
{
  if (Serial.available() > 2)
  {
     //lcd.setCursor(0,3); 
     // lcd.print(Serial.available()); 
    char data = Serial.read();
//    if (data == 'F')  //Flash
//    {
//      int sq = Serial.parseInt();
//      FlashSquare(sq, 50);
//    }
    if (data == 'L') //LED on
    {
      //beep(600,500);
      int sq = Serial.parseInt();
      LightSquare(sq);
      matrix.writeDisplay();
    }
    if (data == 'C')  //LED Off
    {
       int sq = Serial.parseInt();
       ClearLeds();
    }
    if (data == 'B')  //LED Off
    {
       int sq = Serial.parseInt();
       beep(sq);
    }
    if (data == 'D') //LCD Disply
    {
      int sq = Serial.parseInt();
      lcd.setCursor(0,sq);
      String s  = Serial.readString();
      lcd.print(s); 
    }
    if (data == 'F')    //from computer 'from square'
    {
      computermove = true;
      move_from = Serial.parseInt();
      //beep(350, 50);
      LightSquare(move_from);
      matrix.writeDisplay();
    }
    if (data == 'T')  //from computer 'to square'
    {
      move_to = Serial.parseInt();
      computermove = true;
      //LightSquare(sq,true);
      // beep(450,50);
      // matrix.writeDisplay();
    }
  }
}


bool GetButtonMask(void)
{
  long debounceDelay = 200;
  if (sw.buttonmask== buttonsave)
  {
    if((millis() - startTime) > debounceDelay )
     {
       return true;
     }
  }
  else 
  {
    startTime = millis();
    buttonsave=sw.buttonmask;
  }
  return false;
}



void newgame(int color)
{
  int brdsetup=0;
  
  while(brdsetup<32)
  {
    sw.fillMatrix(); //piece positions to matrix
    ClearLeds();
    
    brdsetup=32;
    for(int i=0;i<16;i++)
    {
      if(!sw.GetKeyState(i))  
      {
        brdsetup--;
        LightSquare(i);
      }
    }
     for(int i=48;i<64;i++)
    {
      if(!sw.GetKeyState(i))
     
      {
        brdsetup--;
        LightSquare(i);
      }
    }
    matrix.writeDisplay();
  }
  if(color)   ToPython("newgame:b");
  else ToPython("newgame:w");
}


void  lightled(int row,int column)
{
 
  if(column<8)
  {
    matrix.displaybuffer[column] |= (1<<row);
  }
  else if(row<8)  //column 8
  {
     matrix.displaybuffer[row] |= (1<<9);
  }
  else  //column and row 8
  {
    matrix.displaybuffer[0] |= (1<<10);
  }
}

void ClearLeds()
{
  for(int i=0;i<8;i++)
  {
    matrix.displaybuffer[i] =0;
  }
   matrix.writeDisplay();
}

void FlashSquare(int square, int milliseconds)
{
  ClearLeds();
  LightSquare(square);
  beep(350);
  matrix.writeDisplay();
  //delay(milliseconds);
  ClearLeds();
}
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

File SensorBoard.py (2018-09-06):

___author__ = 'Brian'



import threading
import chess
import time
import logging
import serial
import chess.uci
import smbus
from utilities import *
from timecontrol import *
from picochess import *




class SensorBoard(Observable, threading.Thread):
    def __init__(self):
        super(SensorBoard, self).__init__()
        self.flip_board = False
        self.arduino = serial.Serial('/dev/ttyUSB0', 115200, timeout=.1)

    def Light_Square(self,sq,on):
        if on:
            sq = "L" + str(sq)
            self.arduino.write(str.encode(sq))
        else:
            sq = "C" + str(sq)
            self.arduino.write(str.encode(sq))
        self.arduino.flush()


    def run(self):
        global playersturn
        while True:
            btxt = ""
            if self.arduino.inWaiting()>0:
                btxt = self.arduino.readline().strip()
                self.arduino.flush()
            if btxt:
                #print(btxt)
                cmd = btxt.decode('utf-8').lower()

                #raw = input('PicoChess v' + version + ':>').strip()
                #cmd = raw.lower()
                #print(cmd)
                try:
                    # commands like "newgame:<w|b>" or "setup:<legal_fen_string>"
                    # or "print:<legal_fen_string>"
                    #
                    # for simulating a dgt board use the following commands
                    # "fen:<legal_fen_string>" or "button:<0-4>"
                    #
                    # everything else is regarded as a move string
                    if cmd.startswith('newgame:'):
                        side = cmd.split(':')[1]
                        if side == 'w':
                            #self.flip_board = False
                            #self.fire(Event.FEN(fen='rnbqkbnr/pppppppp/8/8/8/8/PPPPPPPP/RNBQKBNR'))
                            self.fire(Event.NEW_GAME(pos960=518))
                        elif side == 'b':
                            self.fire(Event.NEW_GAME)
                            #self.flip_board = True
                            #self.fire(Event.FEN(fen='RNBKQBNR/PPPPPPPP/8/8/8/8/pppppppp/rnbkqbnr'))
                        else:
                            raise ValueError(cmd)
                    else:
                        # if cmd.startswith('print:'):
                        #     fen = cmd.split(':')[1]
                        #     print(chess.Board(fen))
                        # elif cmd.startswith('setup:'):
                        #     fen = cmd.split(':')[1]
                        #     uci960 = False  # make it easy for the moment
                        #     bit_board = chess.Board(fen, uci960)
                        #     if bit_board.is_valid():
                        #         self.fire(Event.SETUP_POSITION(fen=bit_board.fen(), uci960=uci960))
                        #     else:
                        #         raise ValueError(fen)
                        # Here starts the simulation of a dgt-board!
                        # Let the user send events like the board would do
                        if cmd.startswith('FEN:'):
                            fen = cmd.split(':')[1]
                            # dgt board only sends the basic fen => be sure
                            # it's same no matter what fen the user entered
                            self.fire(Event.FEN(fen=fen.split(' ')[0]))
                        elif cmd.startswith('b:'):
                            button = int(cmd.split(':')[1])
                            if button not in range(6):
                                raise ValueError(button)
                            if button==5:
                                button=0x40
                            self.fire(Event.KEYBOARD_BUTTON(button=button, dev = 'ser'))

                        elif cmd.startswith('l:'):
                            from_square = cmd.split(':')[1]
                            self.fire(Event.LIFT_PIECE(square=from_square))
                        elif cmd.startswith('d:'):
                            to_square = cmd.split(':')[1]
                            self.fire(Event.DROP_PIECE(square=to_square))
                            #print("Drop Piece")
                        #elif cmd.startswith("tb:"):
                        #   self.fire(Event.TAKE_BACK())
                        elif cmd.startswith('shutdown'):
                            self.fire(Event.SHUTDOWN(dev='ser'))
                        elif cmd.startswith('reboot'):
                            self.fire(Event.REBOOT(dev='ser'))
                        elif cmd.startswith('done'):
                            #print("ComputerMove done on board")
                            if keyboard_last_fen is not None:
                                self.fire(Event.KEYBOARD_FEN(fen=keyboard_last_fen))
                        else:
                            move = chess.Move.from_uci(cmd)
                            self.fire(Event.KEYBOARD_MOVE(move=move))
                            #print("command not recognised ", cmd)  #bl
                except ValueError as e:
                    logging.warning('Invalid user input [%s]', cmd)
            time.sleep(.2) # sleep .2s
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

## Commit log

2018-08-20 Add nonDGt code
    [Chessboard.fzz]
2018-09-02 Remove old arduino code
2018-09-06 Fix Bug introduced by training mode
    [SensorBoard.py]

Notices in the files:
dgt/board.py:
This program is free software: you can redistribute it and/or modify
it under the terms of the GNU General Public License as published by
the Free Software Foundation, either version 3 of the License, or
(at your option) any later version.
